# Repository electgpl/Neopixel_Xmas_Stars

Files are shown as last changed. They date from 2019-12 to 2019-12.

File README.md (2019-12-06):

# Neopixel Xmas Stars

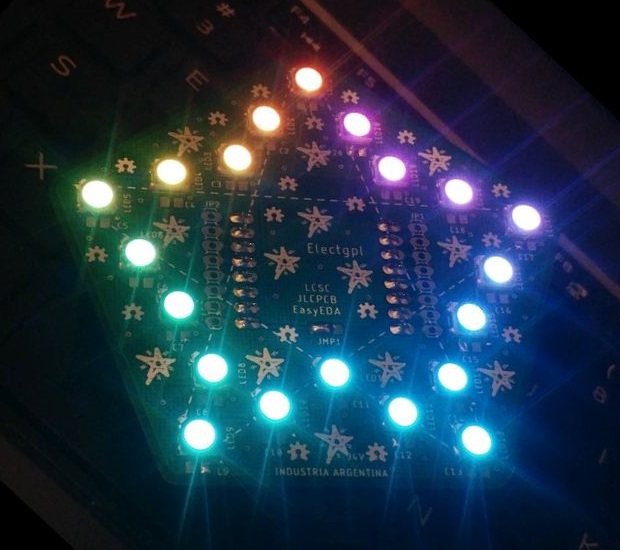
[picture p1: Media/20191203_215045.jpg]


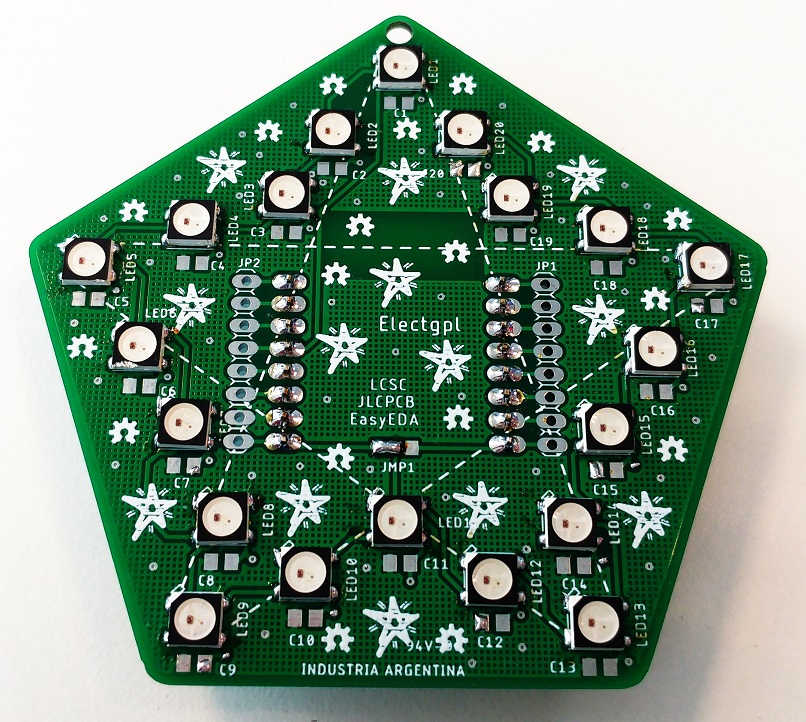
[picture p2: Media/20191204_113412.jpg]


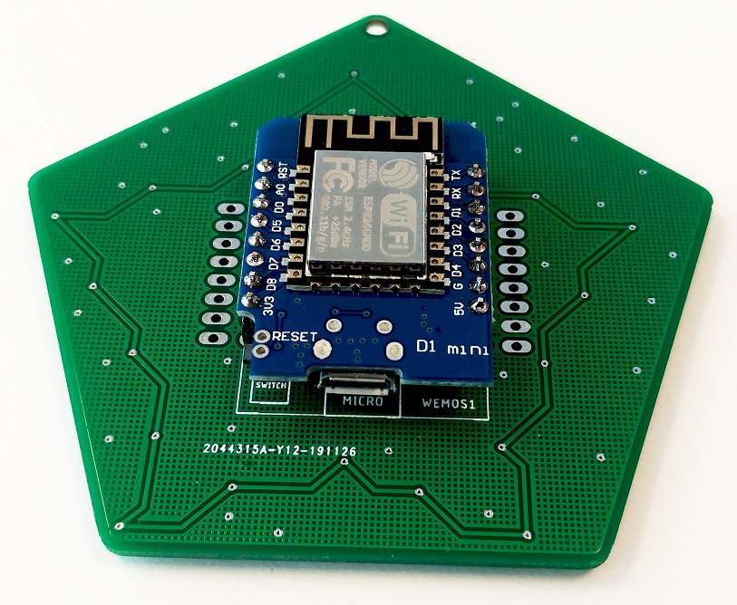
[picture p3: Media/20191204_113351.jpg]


Productos adquiridos en:

N|Solid (https://lcsc.com/?from_code=PL20191029WJJJ)

Este es un proyecto con fines decorativos para Navidad y otros, Se trata de una estrella con 20 Leds inteligentes Neopixel (WS2812) el cual podremos controlar desde Arduino, ESP8266, ESP32, PIC, etc....
En este proyecto estamos usando el Footprint de Wemos D1 Mini (ESP8266), pero se podria cablear cualquier controlador ya que solo se utilizan tres pines de conexion +5V, GND, DataIn.

## IDEs
  - REQUIERE DE LA BIBLIOTECA DE ADAFRUIT "Adafruit_NeoPixel.h"
  - Arduino IDE
  - PlatformIO
  - AtmelStudio
  - y mas...
  
## Diseño y Desarrollo

> Diseñado en dos capas con SMD y THT
> Los componentes SMD son solamente los LEDs 5050 y los capacitores de filtrado (se pueden excluir)
> Los componentes THT son unicamente los pines de coneccion con el WEMOS D1.
>          
> Componentes adquiridos a muy bajo costo en [LCSC].
> PCB creado en [JLCPCB].
> Diseño realizado en [Eagle].

### Instalación

Todos los archivos se encuentran disponibles en este repositorio, diagramas, pcb, programas de ejemplo. etc...

### Pendientes

 - Código de ejemplo puede ser utilizado tanto en Arduino como en Wemos o ESP8266, aunque no se estan usando funciones WiFi.
 - Se pretende generar un nuevo codigo para ESP8266 aprovechando el control por WiFi (WiFiManager, Blynk, etc..)

License
----

MIT

**Free Software, Hell Yeah!**

[LCSC]: <https://lcsc.com/?from_code=PL20191029WJJJ>
[JLCPCB]: <https://jlcpcb.com/>
[Eagle]: <https://www.autodesk.com/products/eagle/overview>

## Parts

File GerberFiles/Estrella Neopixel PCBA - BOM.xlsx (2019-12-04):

Comment | Designator | Footprint | LCSC Part #(optional)
0805B104K500CT | C1, C2, C3, C4, C5, C6, C7, C8, C9, C10, C11, C12, C13, C14, C15, C16, C17, C18, C19, C20 | 0805 | C83055
WS2812B-V3 | LED1, LED2, LED3, LED4, LED5, LED6, LED7, LED8, LED9, LED10, LED11, LED12, LED13, LED14, LED15, LED16, LED17, LED18, LED19, LED20 | 5050 | C114585

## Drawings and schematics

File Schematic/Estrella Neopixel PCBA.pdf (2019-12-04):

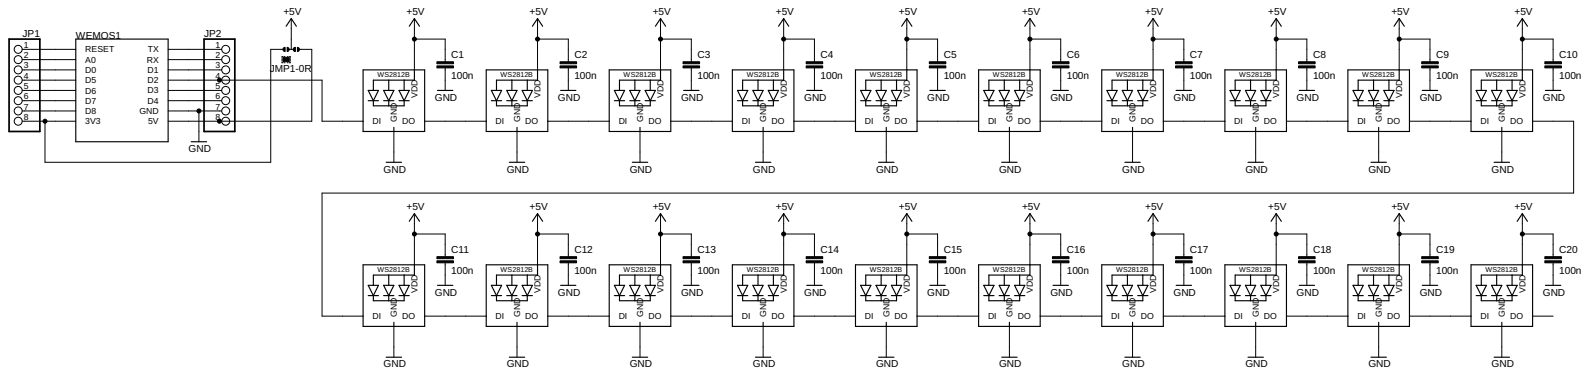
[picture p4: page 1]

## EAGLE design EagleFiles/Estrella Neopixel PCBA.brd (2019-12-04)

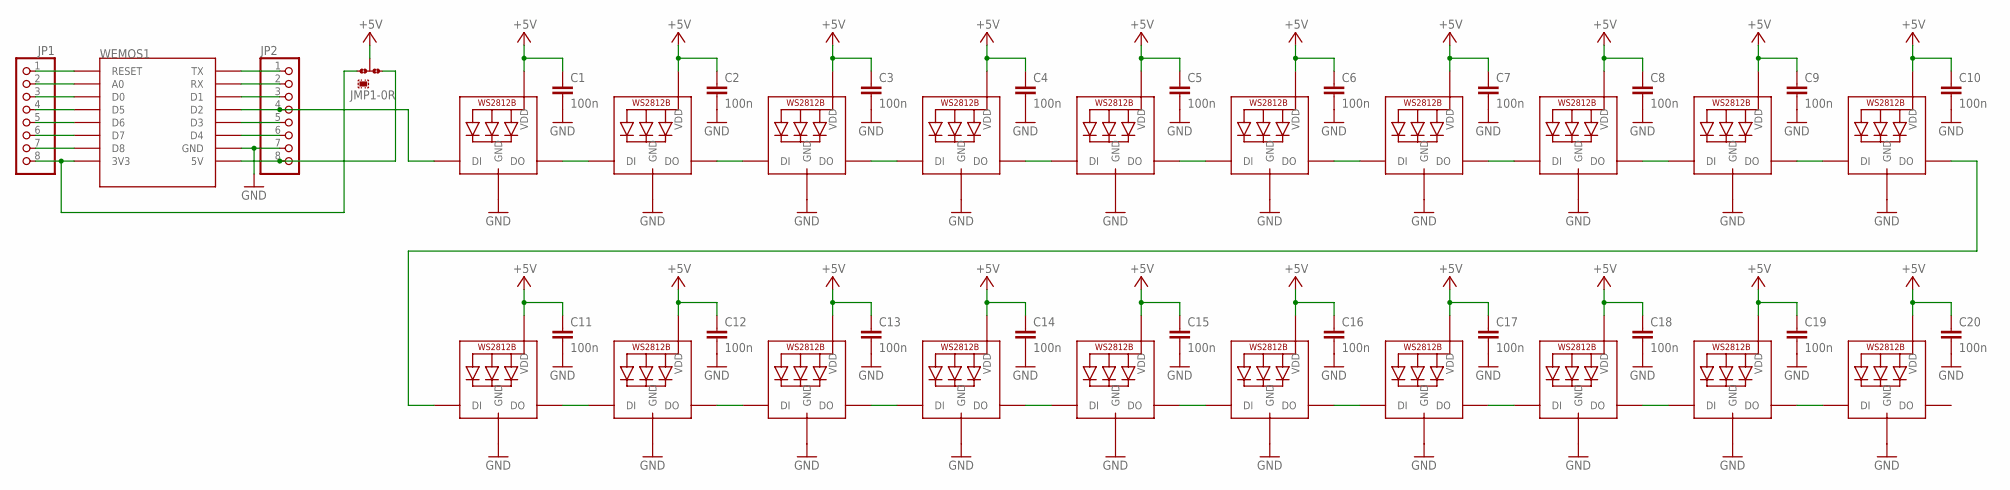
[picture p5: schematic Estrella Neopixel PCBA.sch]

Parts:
C1, C2, C3, C4, C5, C6, C7, C8, C9, C10, C11, C12, C13, C14, C15, C16, C17, C18, C19, C20: 100n; C0805K
JMP1: 0R-JUMPA; A0R-JMP
JP1, JP2: PINHD-1X8; 1X08
LED1, LED2, LED3, LED4, LED5, LED6, LED7, LED8, LED9, LED10, LED11, LED12, LED13, LED14, LED15, LED16, LED17, LED18, LED19, LED20: WS2812B_5050N; WS2812B-NARROW
WEMOS1: WEMOS-D1-MINI

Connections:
+5V: C1.1, C2.1, C3.1, C4.1, C5.1, C6.1, C7.1, C8.1, C9.1, C10.1, C11.1, C12.1, C13.1, C14.1, C15.1, C16.1, C17.1, C18.1, C19.1, C20.1, JMP1.2, LED1.1-VDD (VDD), LED2.1-VDD (VDD), LED3.1-VDD (VDD), LED4.1-VDD (VDD), LED5.1-VDD (VDD), LED6.1-VDD (VDD), LED7.1-VDD (VDD), LED8.1-VDD (VDD), LED9.1-VDD (VDD), LED10.1-VDD (VDD), LED11.1-VDD (VDD), LED12.1-VDD (VDD), LED13.1-VDD (VDD), LED14.1-VDD (VDD), LED15.1-VDD (VDD), LED16.1-VDD (VDD), LED17.1-VDD (VDD), LED18.1-VDD (VDD), LED19.1-VDD (VDD), LED20.1-VDD (VDD)
GND: C1.2, C2.2, C3.2, C4.2, C5.2, C6.2, C7.2, C8.2, C9.2, C10.2, C11.2, C12.2, C13.2, C14.2, C15.2, C16.2, C17.2, C18.2, C19.2, C20.2, JP2.7, LED1.3-GND (GND), LED2.3-GND (GND), LED3.3-GND (GND), LED4.3-GND (GND), LED5.3-GND (GND), LED6.3-GND (GND), LED7.3-GND (GND), LED8.3-GND (GND), LED9.3-GND (GND), LED10.3-GND (GND), LED11.3-GND (GND), LED12.3-GND (GND), LED13.3-GND (GND), LED14.3-GND (GND), LED15.3-GND (GND), LED16.3-GND (GND), LED17.3-GND (GND), LED18.3-GND (GND), LED19.3-GND (GND), LED20.3-GND (GND), WEMOS1.GND
unnamed: LED1.2-DOUT (DO), LED2.4-DIN (DI)
unnamed: LED2.2-DOUT (DO), LED3.4-DIN (DI)
unnamed: LED3.2-DOUT (DO), LED4.4-DIN (DI)
unnamed: LED4.2-DOUT (DO), LED5.4-DIN (DI)
unnamed: LED5.2-DOUT (DO), LED6.4-DIN (DI)
unnamed: LED6.2-DOUT (DO), LED7.4-DIN (DI)
unnamed: LED7.2-DOUT (DO), LED8.4-DIN (DI)
unnamed: LED8.2-DOUT (DO), LED9.4-DIN (DI)
unnamed: LED9.2-DOUT (DO), LED10.4-DIN (DI)
unnamed: LED10.2-DOUT (DO), LED11.4-DIN (DI)
unnamed: LED11.2-DOUT (DO), LED12.4-DIN (DI)
unnamed: LED12.2-DOUT (DO), LED13.4-DIN (DI)
unnamed: LED13.2-DOUT (DO), LED14.4-DIN (DI)
unnamed: LED14.2-DOUT (DO), LED15.4-DIN (DI)
unnamed: LED15.2-DOUT (DO), LED16.4-DIN (DI)
unnamed: JMP1.3, JP2.8, WEMOS1.5V
unnamed: JMP1.1, JP1.8, WEMOS1.3V3
unnamed: JP1.1, WEMOS1.RESET
unnamed: JP1.2, WEMOS1.A0
unnamed: JP1.3, WEMOS1.D0
unnamed: JP1.4, WEMOS1.D5
unnamed: JP1.5, WEMOS1.D6
unnamed: JP1.6, WEMOS1.D7
unnamed: JP1.7, WEMOS1.D8
unnamed: JP2.6, WEMOS1.D4
unnamed: JP2.5, WEMOS1.D3
unnamed: JP2.3, WEMOS1.D1
unnamed: JP2.2, WEMOS1.RX
unnamed: JP2.1, WEMOS1.TX
unnamed: JP2.4, LED1.4-DIN (DI), WEMOS1.D2
unnamed: LED17.2-DOUT (DO), LED18.4-DIN (DI)
unnamed: LED18.2-DOUT (DO), LED19.4-DIN (DI)
unnamed: LED19.2-DOUT (DO), LED20.4-DIN (DI)
unnamed: LED16.2-DOUT (DO), LED17.4-DIN (DI)

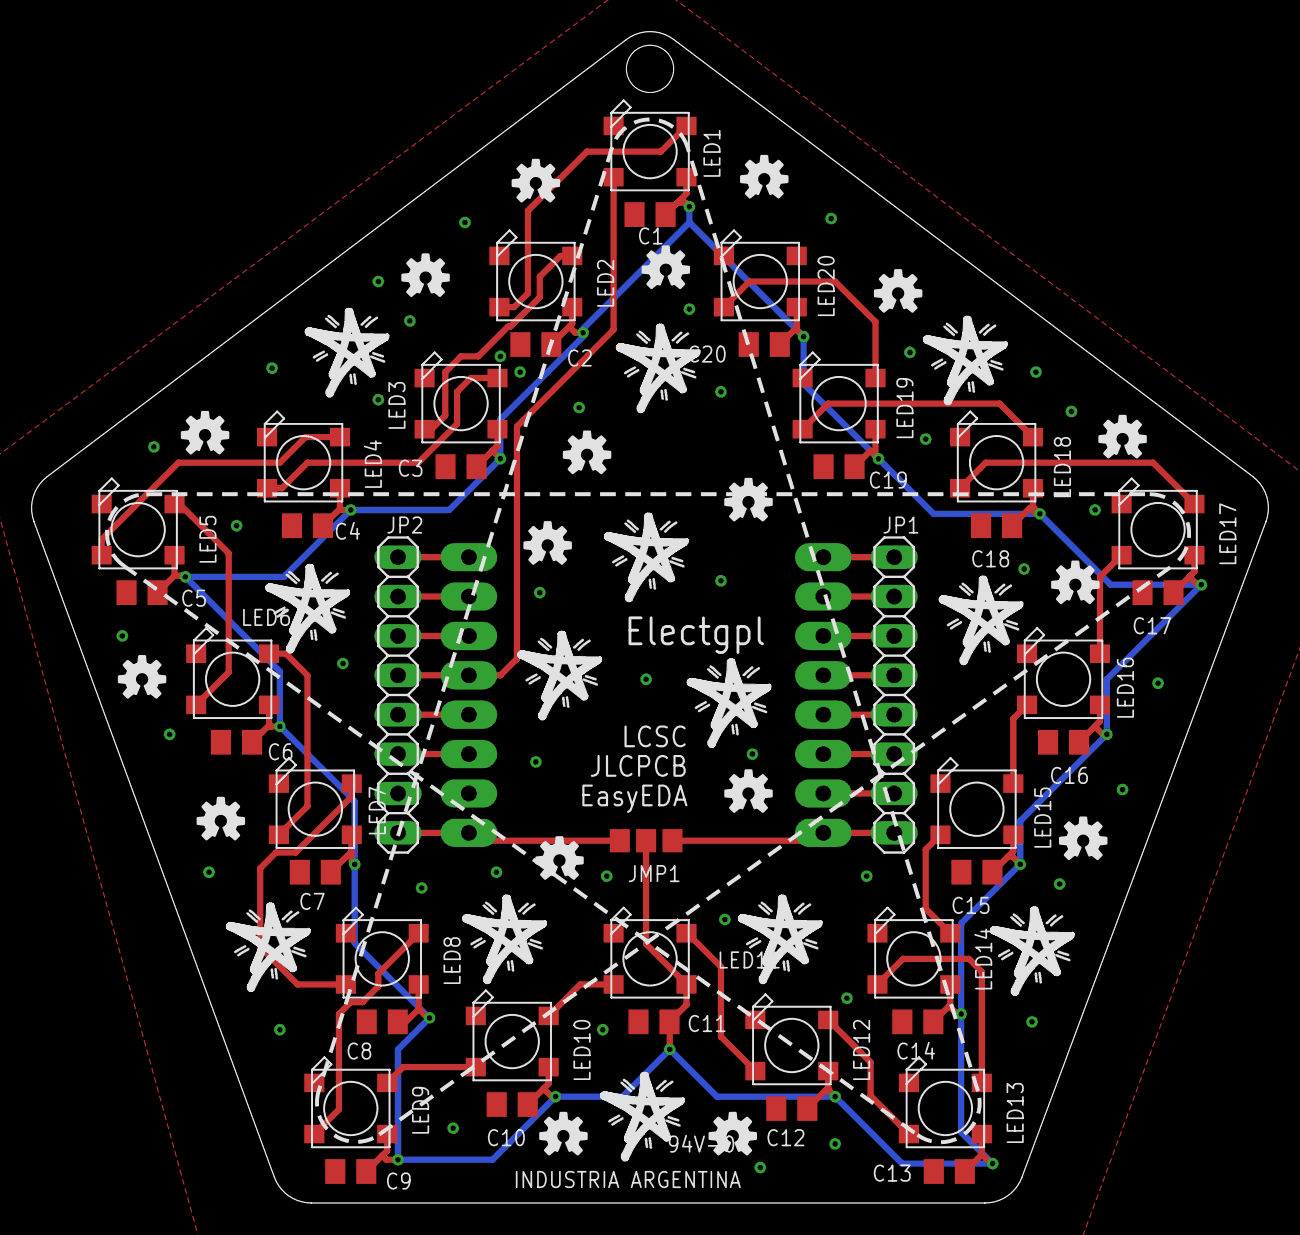
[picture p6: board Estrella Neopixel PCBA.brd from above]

Board: 2 copper layers, 79.8 x 75.6 mm, 75 parts (1 on the bottom side), 36 nets.

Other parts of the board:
U$1, U$2, U$3, U$4, U$5, U$6, U$7, U$8, U$9, U$10, U$13, U$14, U$15: STARBOARD_LOGO
U$11, U$12, U$16, U$17, U$18, U$19, U$20, U$21, U$22, U$23, U$24, U$25, U$26, U$27, U$28, U$29, U$30, U$31: OSHW-LOGO-S

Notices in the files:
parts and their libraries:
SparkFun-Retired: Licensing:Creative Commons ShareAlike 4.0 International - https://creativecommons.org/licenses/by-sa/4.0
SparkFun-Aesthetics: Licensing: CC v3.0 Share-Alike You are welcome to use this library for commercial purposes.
